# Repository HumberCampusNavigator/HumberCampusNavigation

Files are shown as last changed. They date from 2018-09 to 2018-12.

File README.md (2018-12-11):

### Build Instructions for using 'LSM9DS0 9-axis Accelerometer, Magnetometer, Gyroscope & Temperature Sensor' on a Raspberry Pi

whatsapp image 2018-11-20 at 5 41 26 pm

In this Project, the aim is to give step by step instructions to build an hardware unit that measures the values coming from the LSM9DS0 <a href="https://www.adafruit.com/product/2021">sensor</a>. I will be discussing the components needed to build the unit, how much it might cost, various tools that we might need while building up a unit, how to use that tools, and the key factors that should be taken care of . 

Following these six instructions for a student, it might take a couple of days for completion of an hardware unit. But the shipping time of hardware parts will increase the time needed for completion for a student. If it is for mass production, one can use the design and codes readily available with the instructions, and build around 15 units in a single day, provided all parts are readily available.

We will start with the system diagram,

## System Diagram of the Hardware
system diagram paint

  The above diagram explaines how LSM9DS0 sensor can be used to build an hardware unit which can be used to record the readings coming 
from the sensor using a Raspberry Pi. The sensor should be solderedd to an header pin and the header pin's other end should be soldered
to a PCB. The PCB in trun is soldered to another header pin on the opposite side where the sensor is attached. The second header 
pin is then attached to the I/O pins of the Raspberry Pi. This whole unit is enclosed in an acrylic case for safety. The Raspberry Pi
needs power and should be connected to a Virtual connection(wired/wireless) for operating Raspberry Pi remotely by which we can 
read the values coming from the sensor.

## The Components needed to make the Unit and its Cost

  If you are a student of a college or University, you most probably will have a Parts Kit which can be used here. You don't need to buy all those things, that you already have, which reduces the budget significantly. I am including all the components needed for the project, excluding items that are expected to be with students.
  
  All prices are in Canadian Dollars and include Taxes where ever applicable.
  
budget for readme

  You will also need a Laptop or a Desktop to set up the Virtual Connection and operate the Raspberry Pi remotely. Also for printing a 'PCB' and an enclosure(Hard case that holds the entire unit) you might need the help of a Prototype Lab, the cost of which I havent included here. You can get the <a href="https://user-images.githubusercontent.com/43181567/48285231-f46a4080-e42f-11e8-9b14-ac0aec60a713.png">Raspberry Pi</a>, breadboard & Jumper Wires from Amazon.ca and the LSM9DS0 <a href="https://user-images.githubusercontent.com/43181567/48284781-778a9700-e42e-11e8-9d20-d70dc913a38f.jpg">sensor</a> from robotshop.com. There are several online portals that sell these items, you can shop around and find the cheapest one. This data is just for an overall idea about the budget.
  
#### You can see the pictures of the major components below,
### The Sensor
sensor lsm9dso
### The Raspberry Pi
raspberrypi

## Step by Step Instructions for building the Unit.

### Step-1
  The first step is to set up the <a href="https://user-images.githubusercontent.com/43181567/48285231-f46a4080-e42f-11e8-9b14-ac0aec60a713.png">Raspberry Pi</a>. Raspbian is the Operating System for the Raspberry Pi. We will flash Raspbian OS on a 16 GB SD card and insert it into the Raspberry Pi. Raspbian OS is free and can be downloaded online. The flashing instructions can be found <a href="https://www.raspberrypi.org/documentation/installation/installing-images/">here</a> and if the flashing was successfull, when giving power to Raspberry Pi and connecting it to a display, will detect and boot the Raspbian OS automatically. For the first time, we need a mouse and a keyboard connected to Raspberry Pi to set up the Virtual Connection (using VNC Viewer) for Raspberry Pi, by giving input and Wi-Fi credentials. For setting up a virtual connection for remote operation of the unit we need to install VNC Viewer on Raspberry Pi and on the Desktop/Laptop which we use to remotely control Raspberry Pi. The details of how to install and setup VNC viewer can be found by clicking <a href="https://www.raspberrypi.org/documentation/remote-access/vnc/">here</a>.

### Step-2
  Second step is to check whether the <a href="https://user-images.githubusercontent.com/43181567/48284781-778a9700-e42e-11e8-9d20-d70dc913a38f.jpg">sensor</a> is in working condition. First we should <a href="https://www.youtube.com/watch?v=3230nCz3XQA">solder</a> a <a href="https://www.aimagin.com/pin-header-long-single-row.html">9 pin header pin</a> on to the sensor, so that the sensor can be inserted into a breadboard. Before start soldering please read this <a href="https://safety.eng.cam.ac.uk/safe-working/copy_of_soldering-safety">document</a> for your own safety. We need to get the raw readings from the sensor on the specific I2C address of the Raspberry Pi. For that we need to find out the wiring diagram of the Sensor output to the specific pins on the Raspberry Pi. We are expected to get readings in two addresses after the wiring of sensor and <a href="https://user-images.githubusercontent.com/43181567/48285231-f46a4080-e42f-11e8-9b14-ac0aec60a713.png">Raspberry Pi</a> as shown below. The addresses where we get readings are '6a' and '1d' of the Raspberry Pi. To get the readings after connection open a terminal on the Raspberry Pi and give the command 'i2cdetect  -y 1'.
#### Connections:
  - Pin 1 from Raspberry Pi to 3V3 of Sensor
  - Pin 2 from Raspberry Pi to SDA of Sensor
  - Pin 3 from Raspberry Pi to SCL of Sensor
  - Pin 5 from Raspberry Pi to GND of Sensor
  - SDOG from Sensor to GND of Sensor
  
  wiring for readme
  
#### Sensor wired with Raspberry pi
  wired 

#### Readings as Expected
  second1
  
### Step-3
  Once we make sure that our <a href="https://user-images.githubusercontent.com/43181567/48285231-f46a4080-e42f-11e8-9b14-ac0aec60a713.png">Raspberry Pi</a> and <a href="https://user-images.githubusercontent.com/43181567/48284781-778a9700-e42e-11e8-9d20-d70dc913a38f.jpg">sensor</a> is working, we can start the designing of PCB  and <a href="https://www.youtube.com/watch?v=3230nCz3XQA">soldering</a>(Please read <a href="https://safety.eng.cam.ac.uk/safe-working/copy_of_soldering-safety">safety measures</a>) of components. Designing a PCB can be done using fritzing software. Click <a href="http://fritzing.org/learning/">here</a> to get insructions on how to use fritzing. This is the image of the fritzing file generated specifically for this sensor and Raspberry Pi. You can download the below fritzing file from this <a href="https://github.com/HumberCampusNavigator/HumberCampusNavigation/blob/master/Fritzing.zip">link in zip format</a>.
  
  pcb design

  Once you are done with the PCB design, you should take this file to a lab where PCB's can be printed out and get it printed out. Once you get the PCB board printed out, you should solder two header pins onto the PCB. One stack header pin of <a href="https://canada.newark.com/adafruit/2223/40-pin-pi-gpio-stacking-header/dp/31AC4582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">40 pins (two 20 pins in parallel)</a> to be soldered to PCB so that the PCB can be securely attached to the Raspberry Pi. Another single line 10 pin stack header pin to be soldered on the other side of the PCB where the sensor can be attached to the PCB securely. The following images will make the idea clear.
  
  oneone
  twotwo
  blog2

### Step-4
   After attaching the sensor on to the PCB and then the PCB on to the <a href="https://user-images.githubusercontent.com/43181567/48285231-f46a4080-e42f-11e8-9b14-ac0aec60a713.png">Raspberry Pi</a> will take out all wirings and the <a href="https://user-images.githubusercontent.com/43181567/48284781-778a9700-e42e-11e8-9d20-d70dc913a38f.jpg">sensor</a> is now connected to the Raspberry Pi with the help of PCB and header pins which are all soldered each other appropriately to make a single unit. Now in this step we need to install a python software specific for our sensor in the Raspberry Pi so that the software will process the raw signals coming from the sensor into human readable values. The measured values of Accelerometer, Gyroscope, Magnetometer and Temperature are expected. The python software for this is readily available from this <a href="http://ozzmaker.com/python-code-for-berryimu-accelerometer-gyroscope-magnetometer-pressure-sensor/">link</a>. All the necessary instructions for installing the software is given in this link. This software expects an output in the address '6b'. Since we are expecting the reading in '6a' address, a minor change need to be done before running the software. I changed the address from '6b' to '6a' in the file 'adafruit_lsm9ds0.py' and the software detected the readings and outputed the values as shown below.We need to do this because output of the sensor has been changed from '6b' to '6a' by making the SDO_G terminal of the sensor low. If SDO_G terminal of the sensor is not made low, we don't need to make this change to this software. The software file I changed is located at "usr/local/lib/python3.5/dist-packages/adafruit_lsm9ds0.py" on my <a href="https://user-images.githubusercontent.com/43181567/48285231-f46a4080-e42f-11e8-9b14-ac0aec60a713.png">Raspberry Pi</a>. The readings will come when running 'main.py' inside the software.
   whatsapp image 2018-11-19 at 1 35 15 pm 1
   
### Step-5
   Now the next step is the enclosure. It simply means to protect the working piece of your hardware get enclosed in a secure case to protect the unit from external damages. So to do that, you need to design an acrylic case for the <a href="https://user-images.githubusercontent.com/43181567/48285231-f46a4080-e42f-11e8-9b14-ac0aec60a713.png">Raspberry Pi</a> which encloses the <a href="https://user-images.githubusercontent.com/43181567/48284781-778a9700-e42e-11e8-9d20-d70dc913a38f.jpg">sensor</a> attched to the PCB. To design the case, you can use <a href="https://www.coreldraw.com/en/">CorelDraw</a> software. 
   
   Here for this unit there are 6 faces and each faces are designed separately with relative measurements taken for locks that holds the unit as an whole.Before assempling the faces, don't forget to screw the Raspberry Pi to the base piece so that the unit is firm with the whole case.
   
   This is the link to download the <a href="https://www.coreldraw.com/en/">CorelDraw</a> codes for the below design.
https://github.com/HumberCampusNavigator/HumberCampusNavigation/blob/HumberCampusNavigator-CoralDraw/Pi2CaseX6.cdr

#### The design of the case using <a href="https://www.coreldraw.com/en/">CorelDraw</a> software
whatsapp image 2018-11-20 at 5 41 26 pm 1
#### Images of the Hardware Unit built 
whatsapp image 2018-11-20 at 5 41 24 pm
whatsapp image 2018-11-20 at 5 41 25 pm 1
whatsapp image 2018-11-20 at 5 41 25 pm

### Step-6
   The last step is to test the unit after the enclosure so that we can make sure that our hardware unit works perfect. So the testing of the components at the beginning, then after soldering and then at the last are helpfull to make sure that our unit building is progressing fine. This also helps to eliminate errors as we go.

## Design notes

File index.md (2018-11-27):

# HUMBER CAMPUS NAVIGATOR

# Week-13 - Nov-27

This is the link of the Power Point presentation by me to be held next week,
https://github.com/HumberCampusNavigator/HumberCampusNavigation/blob/master/Powerpoint.pptx

# Week-12 - Nov-20
 This week I am supposed to do my enclosure. It simply means to protect the working piece of my hardware enclosed in a secure case to protect the unit from external damages. So to do that, I need to design an acrylic case for my <a href="https://user-images.githubusercontent.com/43181567/48285231-f46a4080-e42f-11e8-9b14-ac0aec60a713.png">Raspberry Pi</a> which encloses the <a href="https://user-images.githubusercontent.com/43181567/48284781-778a9700-e42e-11e8-9d20-d70dc913a38f.jpg">sensor</a> attched to the PCB. To design the case, I used <a href="https://www.coreldraw.com/en/">CorelDraw</a> software provided by the college. Staff of the prototype lab helped to understand the software and were great support. The case design was a good challenge and I now know to design something for 2D printing using the <a href="https://www.coreldraw.com/en/">CorelDraw</a> software. It was a good experience and it was not difficult as expected. I got my case printed on the acrylic material and, I now just need to put the whole unit into the case and lock it. It was an easy job. The board of the Raspberry Pi was screwed to the base of the case to make the unit immovable and intact with the case. The screws were provided by the prototype lab of the college. Now my hardware piece with the case looks beautiful as are in the pictures below.  
 # Images of the Hardware Unit built 
whatsapp image 2018-11-20 at 5 41 24 pm
whatsapp image 2018-11-20 at 5 41 25 pm 1
whatsapp image 2018-11-20 at 5 41 25 pm
whatsapp image 2018-11-20 at 5 41 26 pm
 # Follow this link to download the <a href="https://www.coreldraw.com/en/">CorelDraw</a> codes for the below design.
https://github.com/HumberCampusNavigator/HumberCampusNavigation/blob/HumberCampusNavigator-CoralDraw/Pi2CaseX6.cdr
 # The design of the case using <a href="https://www.coreldraw.com/en/">CorelDraw</a> software
whatsapp image 2018-11-20 at 5 41 26 pm 1
# Week-11 - Nov-19
 Hurray, I could finally get the real values out of the readings from my <a href="https://user-images.githubusercontent.com/43181567/48284781-778a9700-e42e-11e8-9d20-d70dc913a38f.jpg">sensor</a> successfully using a <a href="http://ozzmaker.com/python-code-for-berryimu-accelerometer-gyroscope-magnetometer-pressure-sensor/">software</a>. The readings were got using 'main.py' inside the software. I changed the address from 6B to 6A in the file 'adafruit_lsm9ds0.py' and the software detected the readings and outputed the values as shown below. I needed to do this because in Week-8 of my project, I changed the output of the sensor from 6B to 6A by making the SDO_G terminal low. The software file I changed is located at "usr/local/lib/python3.5/dist-packages/adafruit_lsm9ds0.py" on my <a href="https://user-images.githubusercontent.com/43181567/48285231-f46a4080-e42f-11e8-9b14-ac0aec60a713.png">Raspberry Pi</a>. But it took really long time to figure out what was the error. I am back on my <a href="https://user-images.githubusercontent.com/43181567/47050518-a9ca1100-d16e-11e8-99f8-abb6f7a2d0af.PNG">schedule</a> now. The link of the place from where I downloaded my software is http://ozzmaker.com/python-code-for-berryimu-accelerometer-gyroscope-magnetometer-pressure-sensor/ . Next week, that is tomorrow I need to finish my enclosure.
 whatsapp image 2018-11-19 at 1 35 15 pm 1  
# Week-11 - Nov-13
 As number 13 is considered unlucky, this Nov-13th turned out to be unlucky for me. This week was the power up of the <a href="https://user-images.githubusercontent.com/43181567/48284781-778a9700-e42e-11e8-9d20-d70dc913a38f.jpg">sensor</a> due, unfortunately, I could not get the <a href="http://ozzmaker.com/python-code-for-berryimu-accelerometer-gyroscope-magnetometer-pressure-sensor/">software</a> correctly installed on the <a href="https://user-images.githubusercontent.com/43181567/48285231-f46a4080-e42f-11e8-9b14-ac0aec60a713.png">Raspberry Pi</a> to process the readings from the sensor. Since the specific software could not be installed, I could not complete this week's due. So my project is getting late now. I hope to fix the error in the software and get it working, so that I could be back on <a href="https://user-images.githubusercontent.com/43181567/47050518-a9ca1100-d16e-11e8-99f8-abb6f7a2d0af.PNG">track</a>. The error is displayed below.
 whatsapp image 2018-11-19 at 1 35 14 pm
  I was successfull in getting readings from the sensor, means the raw data. Now I need to try getting the readings using a <a href="http://ozzmaker.com/python-code-for-berryimu-accelerometer-gyroscope-magnetometer-pressure-sensor/">software</a>, and processing the data coming in, and display the values of the readings in decimal values.
  whatsapp image 2018-11-19 at 1 35 15 pm
 # Week-10 - Nov-06
 This week I got the PCB that I <a href="https://user-images.githubusercontent.com/43181567/47764834-57740e80-dc9d-11e8-9220-53d7898e6b8d.png">designed</a> actually built. It was my very first experience like this and was really amazing to have a PCB designed by me itself. After getting the PCB, I soldered my <a href="https://user-images.githubusercontent.com/43181567/48284781-778a9700-e42e-11e8-9d20-d70dc913a38f.jpg">sensor</a> with the PCB, but not directly. I used an header which I soldered on top part of the PCB directly and then I inserted my sensor to the header. Again I soldered another header to the other part of the PCB and connected the header to the pins of <a href="https://user-images.githubusercontent.com/43181567/48285231-f46a4080-e42f-11e8-9b14-ac0aec60a713.png">Raspberry Pi</a>.
 
 blog2
 blog1

 Since there need a connection between the third and eighth pin of the <a href="https://user-images.githubusercontent.com/43181567/48284781-778a9700-e42e-11e8-9d20-d70dc913a38f.jpg">sensor</a>, I needed to connect it on the PCB with a small wire. Actually it is to make the SDO_G pin of the <a href="sensor lsm9dso">sensor</a> low which will give the readings on 6a insted of 6b. Eventhough I made this connection on the PCB, since there was no actual 'VIA' connection, I needed to do this, otherwise need to redesign and make a brand new one. This was a good experience for me which I think will be helpfull in solving real world problems too.
 blog3
# Week-9 - Oct-30
 This week I finished the <a href="https://github.com/HumberCampusNavigator/HumberCampusNavigation/blob/master/Fritzing.fzz">PCB design</a> and send it to Prototype Lab of Humber College for its making. I used the <a href="http://fritzing.org/home/">Fritzing</a> Software to design the PCB. The PCB design can be downloaded by clicking this <a href="https://github.com/HumberCampusNavigator/HumberCampusNavigation/blob/master/Fritzing.fzz">link</a>. One PCB will be attched on to the <a href="https://user-images.githubusercontent.com/43181567/48285231-f46a4080-e42f-11e8-9b14-ac0aec60a713.png">Raspberry Pi</a> and my sensor will be attached to the PCB. The image below is the PCB designed. In the image below, the Orange wires shows wiring under the PCB, that will not be visible after attaching to the <a href="https://user-images.githubusercontent.com/43181567/48285231-f46a4080-e42f-11e8-9b14-ac0aec60a713.png">Raspberry Pi</a>. The Yellow lines are wiring on the top portion of the PCB. The <a href="https://user-images.githubusercontent.com/43181567/48284781-778a9700-e42e-11e8-9d20-d70dc913a38f.jpg">sensor</a> will come on top of the PCB. You could also see the round images with black core, which connects orange lines and yellow lines, which are called 'VIA', are used to connect the wiring from down side of PCB to the top side of PCB.
 
  This week, when I reviewed the <a href="https://user-images.githubusercontent.com/43181567/47050518-a9ca1100-d16e-11e8-99f8-abb6f7a2d0af.PNG">progress</a> of the project, it is a good feeling that the project is progressing as expected. All <a href="https://user-images.githubusercontent.com/43181567/47050518-a9ca1100-d16e-11e8-99f8-abb6f7a2d0af.PNG">milestones</a> are being covered on time. <a href="https://user-images.githubusercontent.com/43181567/47050517-a9ca1100-d16e-11e8-802e-e4492f145e6d.png">The Budget</a> of the project is also as expected. No extra expenses incurred yet.
  
pcb design

# Week-8 - Oct-23
 This week I finished the breadboarding of the <a href="https://user-images.githubusercontent.com/43181567/48284781-778a9700-e42e-11e8-9d20-d70dc913a38f.jpg">sensor</a>, wiring it to the <a href="https://user-images.githubusercontent.com/43181567/48285231-f46a4080-e42f-11e8-9b14-ac0aec60a713.png">Raspberry Pi</a> and connecting the raspberry pi to a screen using HDMI/VGA cables & also through VCN. 
 
 breadboard
 
 After connecting the <a href="https://user-images.githubusercontent.com/43181567/48284781-778a9700-e42e-11e8-9d20-d70dc913a38f.jpg">sensor</a> with the <a href="https://user-images.githubusercontent.com/43181567/48285231-f46a4080-e42f-11e8-9b14-ac0aec60a713.png">Raspberry Pi</a>, I was successfull in getting the readings from the <a href="https://user-images.githubusercontent.com/43181567/48284781-778a9700-e42e-11e8-9d20-d70dc913a38f.jpg">sensor</a>. But the reading that was supposed to be at the location 6A was coming at 6B. This error was rectified by making the terminal SDO_G on the <a href="https://user-images.githubusercontent.com/43181567/48284781-778a9700-e42e-11e8-9d20-d70dc913a38f.jpg">sensor</a> low, ie, by connecting terminal SDO_G to Ground. I also assigned static ip for the raspberry pi because, each time when I connect through VCN, it is easy in future to set up the connection, no need to find the ip address assigned.
 
 # Readings as Expected
second1
 # Readings from Sensor with Unexpected Results
first
 # Sensor wired with Raspberry pi
wired 

# Week-7 - Oct-16

I setup the raspberry pi with the Raspbian Operating System installed on a 16 GB memory card which is  inserted into the memory card slot of the raspberry pi. Further, I recieved all other hardwares ordered during the Week-5 and started to research on the assembly of the breadboard.

# Week-6 - Oct-9

This week I worked on the pseudo codes and UML diagram of the project. There was no class this week as it was our reading week.

# Week-5 - Oct-2

I purchased Raspberry pi from Amazon.ca

amazonbill

I purchased the <a href="https://user-images.githubusercontent.com/43181567/48284781-778a9700-e42e-11e8-9d20-d70dc913a38f.jpg">sensor</a> from robotshop.com

robotshopbill

# Week-4 - Sept-25

Here is the Budget for my Project

budget

# Week-3 - Sept-18

Here is the Project Schedule/Gantt Chart for the project

gantt chart

# Week-2 - Sept-11

The Proposal of the project is given below. In this project, the android application will get readings from a sensor and will display it to the users while using the application. The sensor that I am using is <a href="https://www.adafruit.com/product/2021">LSM9DSO</a>. Details about the sensor can be found in https://www.adafruit.com/product/2021 .In this project I am building an hardware unit which reads the data from the sensors and tranfer it to a database so that the application can read from the database. For this I need a Raspberry pi and the sensor as the main components and then some wires and a PCB to power up the unit and to connect the components together.
 # The Sensor
sensor lsm9dso
 # The Raspberry Pi
raspberrypi
 # The Proposal
proposal

# Week-1 - Sept-04

The idea of the project was discussed with the professor and group members were finalised. 
The name of the project was decided as, 
# HUMBER CAMPUS NAVIGATOR

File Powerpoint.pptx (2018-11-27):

## Sensor-LSM9DS0

The 9-axis Accelerometer, Magnetometer & Gyroscope
With Temperature Sensing

## The Sensor

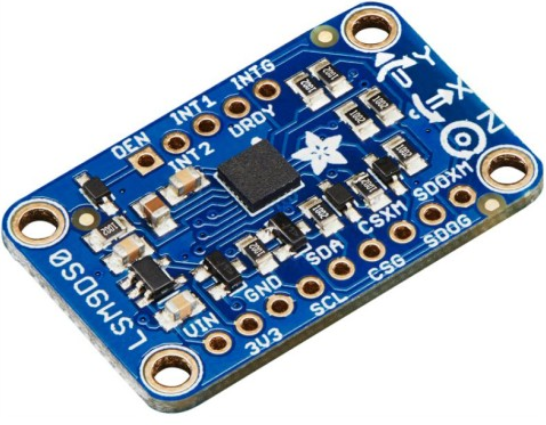
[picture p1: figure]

## The Budget to use this sensor readings and convert it into human readable values

- 1. LSM9DS0 sensor - C$ 27
- 2. Raspberry Pi Kit - C$ 87
- 3. Jumper Wires - C$ 04
- 4. Solderless Breadboard - C$ 05
- 5. Shipping Charges - C$ 19
- Total - C$ 142

## The Schedule

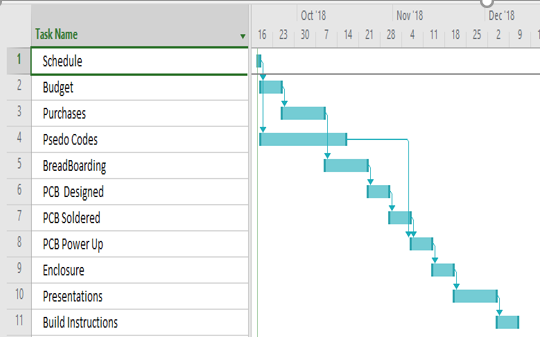
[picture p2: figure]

## Major Challenges

- 1. The raw readings of the sensor was coming at ‘6b’ address instead of ‘6a’ address.
  - Solution- Connected SDOG terminal of the sensor to Ground and the error was corrected.
- 2. When the python software was installed in Raspberry Pi to process the signals from the sensor, there was a value error.
  - Solution- The address in the file ‘adafruit_lsm9ds0.py’ need to be changed from ‘6b’ to ‘6a’ since we changed the raw data from sensor from ‘6b’ to ‘6a’.

## How I Could Do This

- Sem1- Tech 101(Electric), Tech103(Digital), Esol120(English)
- Sem2- Tech153(Technical C), Esol220(English)
- Sem3- Ceng215(Digital), Ceng216(Software Eng.)
- Sem4- Ceng250(PC OS & Internals) , Ceng252(Embedded)

## The Final Unit with Readings

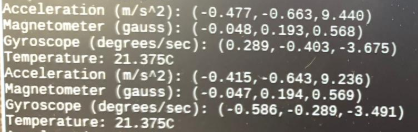
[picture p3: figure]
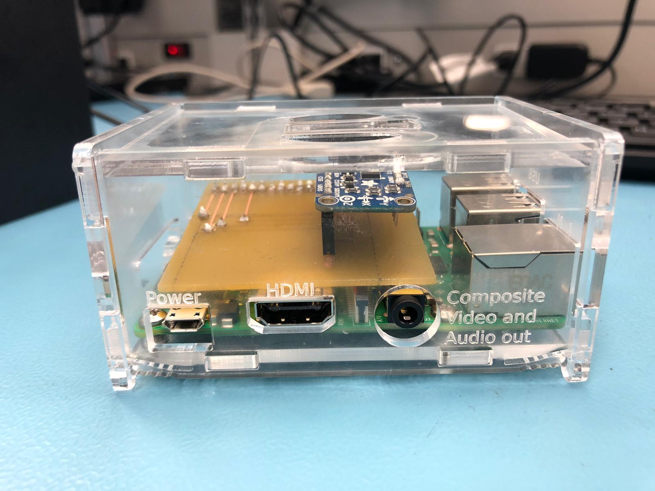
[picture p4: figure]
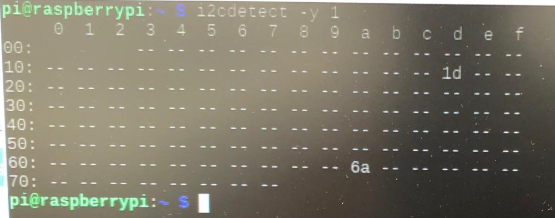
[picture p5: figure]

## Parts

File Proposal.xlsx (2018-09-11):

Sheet: DataEntry
Submission Date | 2018-09-11
Project Name | Humber Campus Navigator
Student Name | Bettin Jacob
Project repository | https://github.com/HumberCampusNavigator/North
SensorEffector choice | LSM9DS0 9-axis IMU (0x1D for Accel/Mag, *0x6A for Gyro).
The database will store | Map of the Humber Campus, Phone numbers
The mobile device functionality will include | Navigation within the campus
I will be collaborating with the following company/department | Wish to work with Humber College Facilities or FYE
My group in the winter semester will include | Ishan Khuttan & Anoopjot Kaur
50 word problem statement | For students it is really hard to navigate within the campus. We are designing an application which helps students to navigate within the campus from any point to any point in short time and less distance.
100 words of background | When we were new to college, we used to roam inside the campus to find anything within the campus. It was really tiresome. Even in this semester it was difficult for me in finding the location of NB part of the college.
Current product APA citation | Jana S., & Chattopadhyay M.(2015). An event-driven university campus navigation system on android platform.Retrieved from https://ieeexplore.ieee.org/document/7083850/
Existing research IEEE paper APA citation | Dionido, R.S., & Ramos, M. C.(2017). Autonomous seed-planting vehicle. Retrieved from https://ieeexplore.ieee.org/document/8284391/
Brief description of planned purchases | 1. Raspberry pi kit with touch screen 2. Some sensors
Solution description | We have two solutions in mind. 1. Real time Navigation - with location sensors installed in various locations of campus, through a mobile app, we can give a real time navigation guidance for users. But this will be expensive. 2. Offline Navigation - With QR code sticked to all the class room doors of the campus, user can just scan the QR code where he stands and select a location anywhere on campus and the app will give the easiest path to that location.
JIMB0(2013). LSM9DSO Hookup Guide. Retrieved from https://learn.sparkfun.com/tutorials/lsm9ds0-hookup-guide

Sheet: DataBase
Submission Date | Project Name | Student Name | Project repository | SensorEffector choice | The database will store | The mobile device functionality will include | I will be collaborating with the following company/department | My group in the winter semester will include | 50 word problem statement | 100 words of background | Current product APA citation | Existing research IEEE paper APA citation | Brief description of planned purchases | Solution description
43354 | Humber Campus Navigator | Bettin Jacob | https://github.com/HumberCampusNavigator/North | LSM9DS0 9-axis IMU (0x1D for Accel/Mag, *0x6A for Gyro). | Map of the Humber Campus, Phone numbers | Navigation within the campus | Wish to work with Humber College Facilities or FYE | Ishan Khuttan & Anoopjot Kaur | For students it is really hard to navigate within the campus. We are designing an application which helps students to navigate within the campus from any point to any point in short time and less distance. | When we were new to college, we used to roam inside the campus to find anything within the campus. It was really tiresome. Even in this semester it was difficult for me in finding the location of NB part of the college. | Jana S., & Chattopadhyay M.(2015). An event-driven university campus navigation system on android platform.Retrieved from https://ieeexplore.ieee.org/document/7083850/ | Dionido, R.S., & Ramos, M. C.(2017). Autonomous seed-planting vehicle. Retrieved from https://ieeexplore.ieee.org/document/8284391/ | 1. Raspberry pi kit with touch screen 2. Some sensors | We have two solutions in mind. 1. Real time Navigation - with location sensors installed in various locations of campus, through a mobile app, we can give a real time navigation guidance for users. But this will be expensive. 2. Offline Navigation - With QR code sticked to all the class room doors of the campus, user can just scan the QR code where he stands and select a location anywhere on campus and the app will give the easiest path to that location.

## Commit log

2018-11-21 Create Case Design-CorelDraw
2018-11-21 Update Case Design-CorelDraw
2018-11-27 Create PowerPoint Presentation
